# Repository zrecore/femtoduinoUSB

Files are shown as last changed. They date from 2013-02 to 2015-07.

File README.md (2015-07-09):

femtoduinoUSB
=============

Latest revision: FemtoduinoUSB r14.2

See the FemtoduinoUSB_r14 folder. It is a 4-layer EAGLE PCB design + schematic.

FemtoduinoUSB ATMEGA328P-MU Arduino Clone. Originally based on the Femtoduino by Fabio Varesano. Modified by Alex Albino to include FTDI USB to serial integration.

The femtoduino, and femtoduinoUSB is released under the following license: 

   CC-BY-SA 3.0 Unported
   http://creativecommons.org/licenses/by-sa/3.0/

The USB to UART circuit was completed in part thanks to Jim Paris' super-awesome MicroFTX schematics (http://jim.sh/ftx/), which are released under the following license:

   Creative Commons Attribution-ShareAlike 3.0 Unported License
   http://creativecommons.org/licenses/by-sa/3.0/
The pins on the latest revision are corrected to align perfectly with the original Femtoduino pin positions.

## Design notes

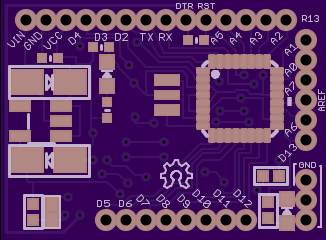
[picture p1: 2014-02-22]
FemtoduinoUSB_r13/femtoduino-usb_front.png

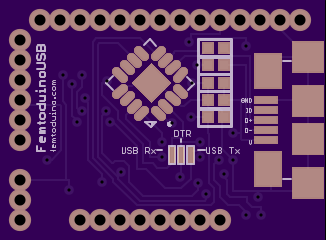
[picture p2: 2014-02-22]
FemtoduinoUSB_r13/femtoduino-usb_back.png

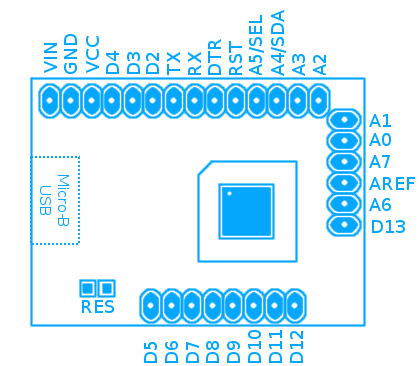
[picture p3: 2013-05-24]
FemtoduinoUSB_r13/femtoduinoUSB_pins.png

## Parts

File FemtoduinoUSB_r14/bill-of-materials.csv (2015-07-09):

Qty | Value | Device/Manufacturer | Package | Parts | Description
7 | 0.1uF | C1005X7R1A104K050BB | 0402 | C1, C2, C3, C4, C5, C6, C7 | Ceramic Capacitors
1 | DNP |  |  | U$4
1 | DNP |  |  | U$2
1 | DNP |  |  | U$3
1 | DNP |  |  | U$28
1 | 10K | CRCW040210K0JNEDHP | _0402 | R4 | Resistors
2 | 10uF | TAJA106K016RNJ | EIA3216-18/A-R | C8, C9 | Tantalum Capacitors
2 | 27 | CRCW040227R0FKED | 0402 | R1, R2 | Resistors
2 | 330 | CRCW0402330RJNED | 0402 | R3, R5 | Resistors
1 | ATMEGA328MLF | ATMEGA328P-MU | MLF32 | U1 | Atmel 32-pin 8-bit micro, 32k flash.
1 | 16MHz | CSTCE16M0V51-R0 | CSTCE16M0V51-R0_PACKAGE | U$22 | This is the CSTCE16M0V51-R0 Murata resonator (CERALOCK) 16Mhz 0.5% Tolerance
1 | GREEN | 598-8070-102F | 0603 | LED2 | LED
1 | FT230XQ | FT230XQ-R | QFN-16 | U$1
1 | LDO_REGULATOR | TPS76350DBVR | SOT-23-5 | U$10
1 | RED | 598-8010-102F | 0603 | LED1 | LED
1 | DNP |  |  | U$17
1 | USB_MICROB | ZX62-B-5PA(11) | USB_MICROB_PACKAGE | U$6 | This is the hirose ZX62-B-5PA(11) MICRO-USB B Type female connection.

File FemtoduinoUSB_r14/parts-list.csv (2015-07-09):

Part | Value | Device/Manufacturer | Package | Description
C1 | 0.1uF | C1005X7R1A104K050BB | 0402 | Ceramic Capacitors
C2 | 0.1uF | C1005X7R1A104K050BB | 0402 | Ceramic Capacitors
C3 | 0.1uF | C1005X7R1A104K050BB | 0402 | Ceramic Capacitors
C4 | 0.1uF | C1005X7R1A104K050BB | 0402 | Ceramic Capacitors
C5 | 0.1uF | C1005X7R1A104K050BB | 0402 | Ceramic Capacitors
C6 | 0.1uF | C1005X7R1A104K050BB | 0402 | Ceramic Capacitors
C7 | 0.1uF | C1005X7R1A104K050BB | 0402 | Ceramic Capacitors
C8 | 10uF | TAJA106K016RNJ | EIA3216-18/A-R | Tantalum Capacitors
C9 | 10uF | TAJA106K016RNJ | EIA3216-18/A-R | Tantalum Capacitors
LED1 | RED | 598-8010-102F | 0603 | LED
LED2 | GREEN | 598-8070-102F | 0603 | LED
R1 | 27 | CRCW040227R0FKED | 0402 | Resistors
R2 | 27 | CRCW040227R0FKED | 0402 | Resistors
R3 | 330 | CRCW0402330RJNED | 0402 | Resistors
R4 | 10K | CRCW040210K0JNEDHP | 0402 | Resistors
R5 | 330 | CRCW0402330RJNED | 0402 | Resistors
U$1 | FT230XQ | FT230XQ-R | QFN-16
U$2 | DNP
U$3 | DNP
U$4 | DNP
U$6 | USB_MICROB | ZX62-B-5PA(11) | USB_MICROB_PACKAGE | This is the hirose ZX62-B-5PA(11) MICRO-USB B Type female connection.
U$10 | LDO_REGULATOR | TPS76350DBVR | LDO_REGULATOR
U$17 | DNP
U$22 | 16MHz | CSTCE16M0V51-R0 | CSTCE16M0V51-RO_PACKAGE | This is the CSTCE16M0V51-R0 Murata resonator (CERALOCK) 16Mhz 0.5% Tolerance
U$28 | DNP
U1 | ATMEGA328MLF | ATMEGA328P-MU | MLF32 | Atmel 32-pin 8-bit micro, 32k flash.

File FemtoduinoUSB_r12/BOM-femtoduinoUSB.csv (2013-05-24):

Part | Value | Device | Mfr. | Mfr.# | Package | Description
C1 | 10uF | CAP_TANTALUMB/3528_WAVE | AVX | TAJA106K016RNJ | EIA3528-21/B-W | Tantalum Capacitors
C2 | 10uF | CAP_TANTALUMB/3528_WAVE | AVX | TAJA106K016RNJ | EIA3528-21/B-W | Tantalum Capacitors
C3 | 0.1uF | CAP_CERAMIC0402 | TDK | C1005X7R1A104K | 402 | Ceramic Capacitors
C4 | 0.1uF | CAP_CERAMIC0402 | TDK | C1005X7R1A104K | 402 | Ceramic Capacitors
C5 | 0.1uF | CAP_CERAMIC0402 | TDK | C1005X7R1A104K | 402 | Ceramic Capacitors
C6 | 0.1uF | CAP_CERAMIC0402 | TDK | C1005X7R1A104K | 402 | Ceramic Capacitors
C7 | 0.1uF | CAP_CERAMIC0402 | TDK | C1005X7R1A104K | 402 | Ceramic Capacitors
C8 | 0.1uF | CAP_CERAMIC0402 | TDK | C1005X7R1A104K | 402 | Ceramic Capacitors
C9 | 0.1uF | CAP_CERAMIC0402 | TDK | C1005X7R1A104K | 402 | Ceramic Capacitors
IC1 |  | ATMEGA168MLF | Atmel | ATMEGA328P-MU | MLF32 | Atmel 32-pin 8-bit micro | 16k flash.
LED1 | D1 | LED0805 | Dialight | 598-8110-107F | CHIPLED_0805 | LED
LED2 |  | LED0805 | Dialight | 598-8170-107F | CHIPLED_0805 | LED
R1 | 330 | RESISTOR0402 | Vishay | CRCW0402330RJNED | 402 | Resistors
R2 | 10K | RESISTOR0402 | Vishay | CRCW040210K0JNEDHP | 402 | Resistors
R3 | 330 | RESISTOR0402 | Vishay | CRCW0402330RJNED | 402 | Resistors
R4 | 27 | RESISTOR0402 | Vishay | CRCW040227R0FKED | 402 | Resistors
R5 | 27 | RESISTOR0402 | Vishay | CRCW040227R0FKED | 402 | Resistors
SJ1 | SPST_SMD | SPST_SMD |  |  | SPST_SMD
SJ2 | SPST_SMD | SPST_SMD |  |  | SPST_SMD
SJ3 | SPST_SMD | SPST_SMD |  |  | SPST_SMD
SJ4 | SPST_SMD | SPST_SMD |  |  | SPST_SMD
U$2 | 05_PINHEAD_1X6 | 05_PINHEAD_1X6 |  |  | 05_PINHEAD_1X6_PACKAGE
U$3 | 05_PINHEAD_1X8 | 05_PINHEAD_1X8 |  |  | 05_PINHEAD_1X8_PACKAGE
U$4 | 05_PINHEAD_1X14 | 05_PINHEAD_1X14 |  |  | 05_PINHEAD_1X14_PACKAGE
U$5 | CSTCE16MOV51-RO | CSTCE16MOV51-RO | Murata | CSTCE16M0V51-R0 | CSTCE16M0V51-RO_PACKAGE | This is the CSTCE16M0V51-R0 Murata resonator (CERALOCK) 16Mhz 0.5% Tolerance
U$6 | SPST_SMD | SPST_SMD |  |  | SPST_SMD
U$7 | FT230XQ | FT230XQ | FTDI | FT230XQ-R | FT230XQ
U1 | MIC5205 | LDO_REGULATOR | Texas Instruments | TPS76350DBVR | LDO_REGULATOR
USB1 | USB_MICROB | USB_MICROB | Hirose Electric | ZX62-B-5PA(11) | USB_MICROB_PACKAGE | This is the hirose ZX62-B-5PA(11) MICRO-USB B Type female connection.

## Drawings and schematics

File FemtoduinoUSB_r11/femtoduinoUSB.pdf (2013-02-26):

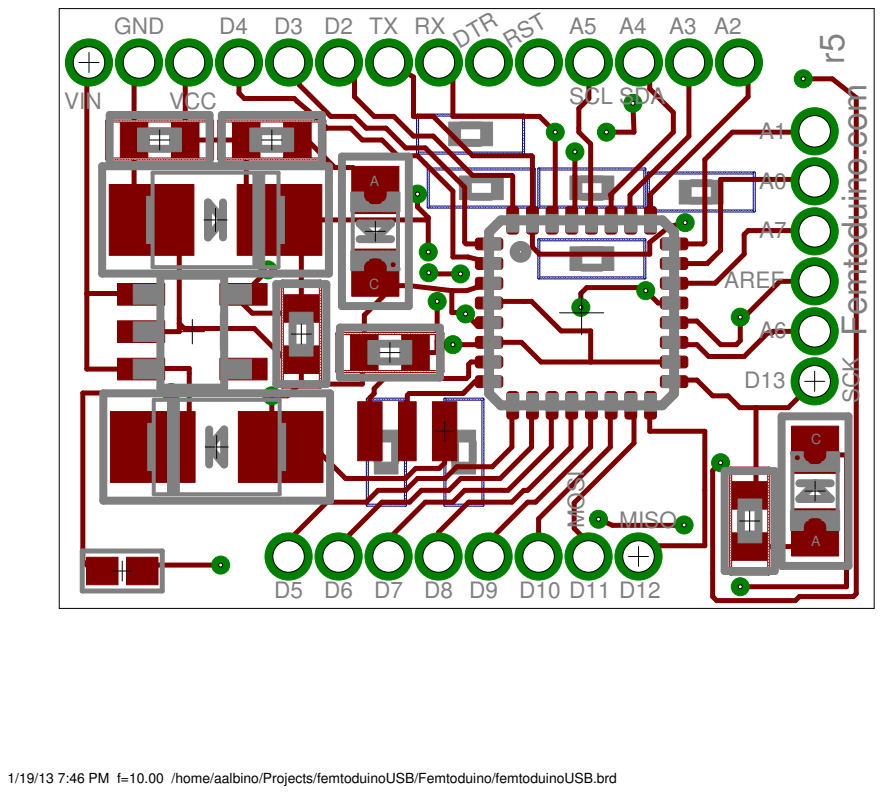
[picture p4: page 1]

1/19/13 7:46 PM f=10.00 /home/aalbino/Projects/femtoduinoUSB/Femtoduino/femtoduinoUSB.brd

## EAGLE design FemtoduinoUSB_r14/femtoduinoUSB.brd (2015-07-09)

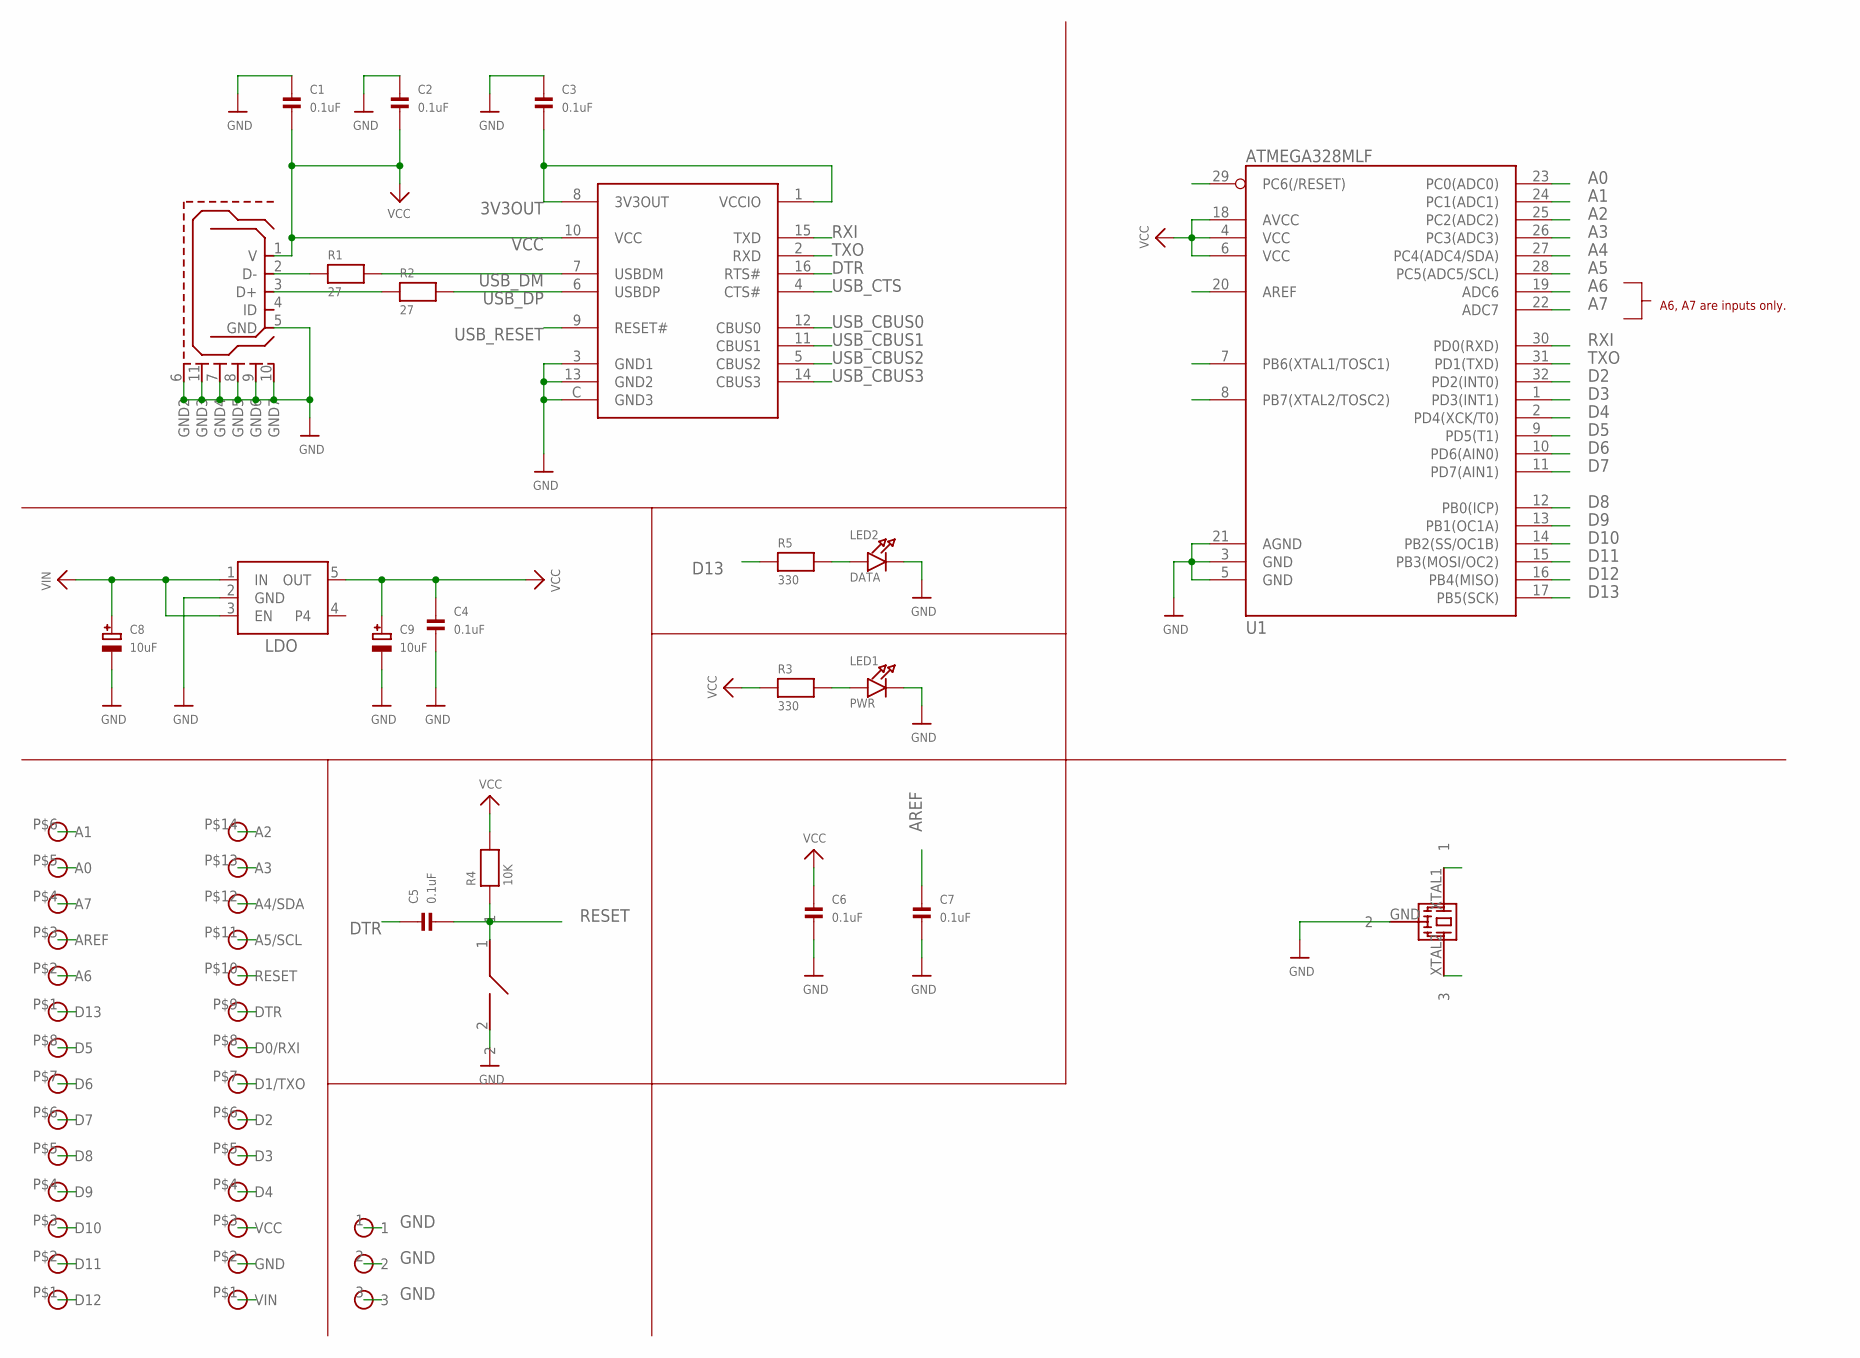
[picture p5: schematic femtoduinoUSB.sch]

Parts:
C1, C2, C3, C4, C5, C6, C7: 0.1uF; _0402MP
C8, C9: 10uF; EIA3216-18/A-R
LED1: PWR; CHIPLED_0603_NOOUTLINE
LED2: DATA; CHIPLED_0603_NOOUTLINE
R1, R2: 27; _0402MP
R3, R5: 330; _0402MP
R4: 10K; _0402
U1: ATMEGA328MLF; MLF32
U$1: FT230XQ
U$2: 05_PINHEAD_1X6; 05_PINHEAD_1X6_PACKAGE
U$3: 05_PINHEAD_1X8; 05_PINHEAD_1X8_PACKAGE
U$4: 05_PINHEAD_1X14; 05_PINHEAD_1X14_PACKAGE
U$6: USB_MICROB; USB_MICROB_PACKAGE
U$10: LDO_REGULATOR
U$17: SPST_SMD
U$22: CSTCE16MOV51-RO; CSTCE16M0V51-RO_PACKAGE
U$28: 05_PINHEAD_HEADER_1X3; 05_PINHEAD_1X3_HEAD_PACKAGE

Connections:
3V3OUT: C3.2, U$1.1 (VCCIO), U$1.8 (3V3OUT)
A0: U1.23 (PC0(ADC0)), U$2.P$5 (A0)
A1: U1.24 (PC1(ADC1)), U$2.P$6 (A1)
A2: U1.25 (PC2(ADC2)), U$4.P$14 (A2)
A3: U1.26 (PC3(ADC3)), U$4.P$13 (A3)
A4: U1.27 (PC4(ADC4/SDA)), U$4.P$12 (A4/SDA)
A5: U1.28 (PC5(ADC5/SCL)), U$4.P$11 (A5/SCL)
A6: U1.19 (ADC6), U$2.P$2 (A6)
A7: U1.22 (ADC7), U$2.P$4 (A7)
AREF: C7.1, U1.20 (AREF), U$2.P$3 (AREF)
D2: U1.32 (PD2(INT0)), U$4.P$6 (D2)
D3: U1.1 (PD3(INT1)), U$4.P$5 (D3)
D4: U1.2 (PD4(XCK/T0)), U$4.P$4 (D4)
D5: U1.9 (PD5(T1)), U$3.P$8 (D5)
D6: U1.10 (PD6(AIN0)), U$3.P$7 (D6)
D7: U1.11 (PD7(AIN1)), U$3.P$6 (D7)
D8: U1.12 (PB0(ICP)), U$3.P$5 (D8)
D9: U1.13 (PB1(OC1A)), U$3.P$4 (D9)
D10: U1.14 (PB2(SS/OC1B)), U$3.P$3 (D10)
D11: U1.15 (PB3(MOSI/OC2)), U$3.P$2 (D11)
D12: U1.16 (PB4(MISO)), U$3.P$1 (D12)
D13: R5.1, U1.17 (PB5(SCK)), U$2.P$1 (D13)
DTR: C5.1, U$1.16 (RTS#), U$4.P$9 (DTR)
GND: C1.1, C2.1, C3.1, C4.2, C6.2, C7.2, C8.-, C9.-, LED1.C, LED2.C, U1.3 (GND), U1.5 (GND), U1.21 (AGND), U$1.3 (GND1), U$1.13 (GND2), U$1.C (GND3), U$4.P$2 (GND), U$6.5 (GND), U$6.6 (GND2), U$6.7 (GND4), U$6.8 (GND5), U$6.9 (GND6), U$6.10 (GND7), U$6.11 (GND3), U$10.2 (GND), U$17.2, U$22.GND (2), U$28.1, U$28.2, U$28.3
unnamed: R1.1, U$6.2 (D-)
unnamed: R2.1, U$6.3 (D+)
unnamed: LED2.A, R5.2
unnamed: LED1.A, R3.2
RESET: C5.2, R4.1, U1.29 (PC6(/RESET)), U$4.P$10 (RESET), U$17.1
RXI: U1.30 (PD0(RXD)), U$1.15 (TXD), U$4.P$8 (D0/RXI)
TXO: U1.31 (PD1(TXD)), U$1.2 (RXD), U$4.P$7 (D1/TXO)
USB_CBUS0: U$1.12 (CBUS0)
USB_CBUS1: U$1.11 (CBUS1)
USB_CBUS2: U$1.5 (CBUS2)
USB_CBUS3: U$1.14 (CBUS3)
USB_CTS: U$1.4 (CTS#)
USB_DM: R1.2, U$1.7 (USBDM)
USB_DP: R2.2, U$1.6 (USBDP)
USB_RESET: U$1.9 (RESET#)
VCC: C1.2, C2.2, C4.1, C6.1, C9.+, R3.1, R4.2, U1.4 (VCC), U1.6 (VCC), U1.18 (AVCC), U$1.10 (VCC), U$4.P$3 (VCC), U$6.1 (V), U$10.5 (OUT)
VIN: C8.+, U$4.P$1 (VIN), U$10.1 (IN), U$10.3 (EN)
XTAL1: U1.7 (PB6(XTAL1/TOSC1)), U$22.XTAL1 (1)
XTAL2: U1.8 (PB7(XTAL2/TOSC2)), U$22.XTAL2 (3)

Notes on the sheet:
A6, A7 are inputs only.

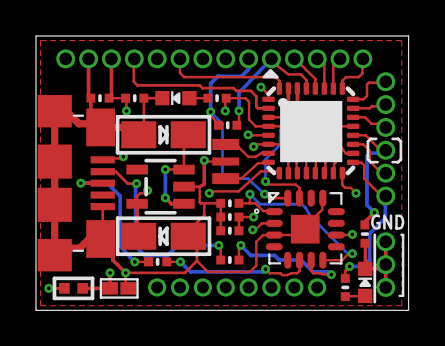
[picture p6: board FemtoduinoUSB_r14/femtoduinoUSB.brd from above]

Board: 4 copper layers, 20.7 x 15.2 mm, 27 parts (1 on the bottom side), 37 nets.

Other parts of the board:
U$29: OSHW_6X70_NOTEXT

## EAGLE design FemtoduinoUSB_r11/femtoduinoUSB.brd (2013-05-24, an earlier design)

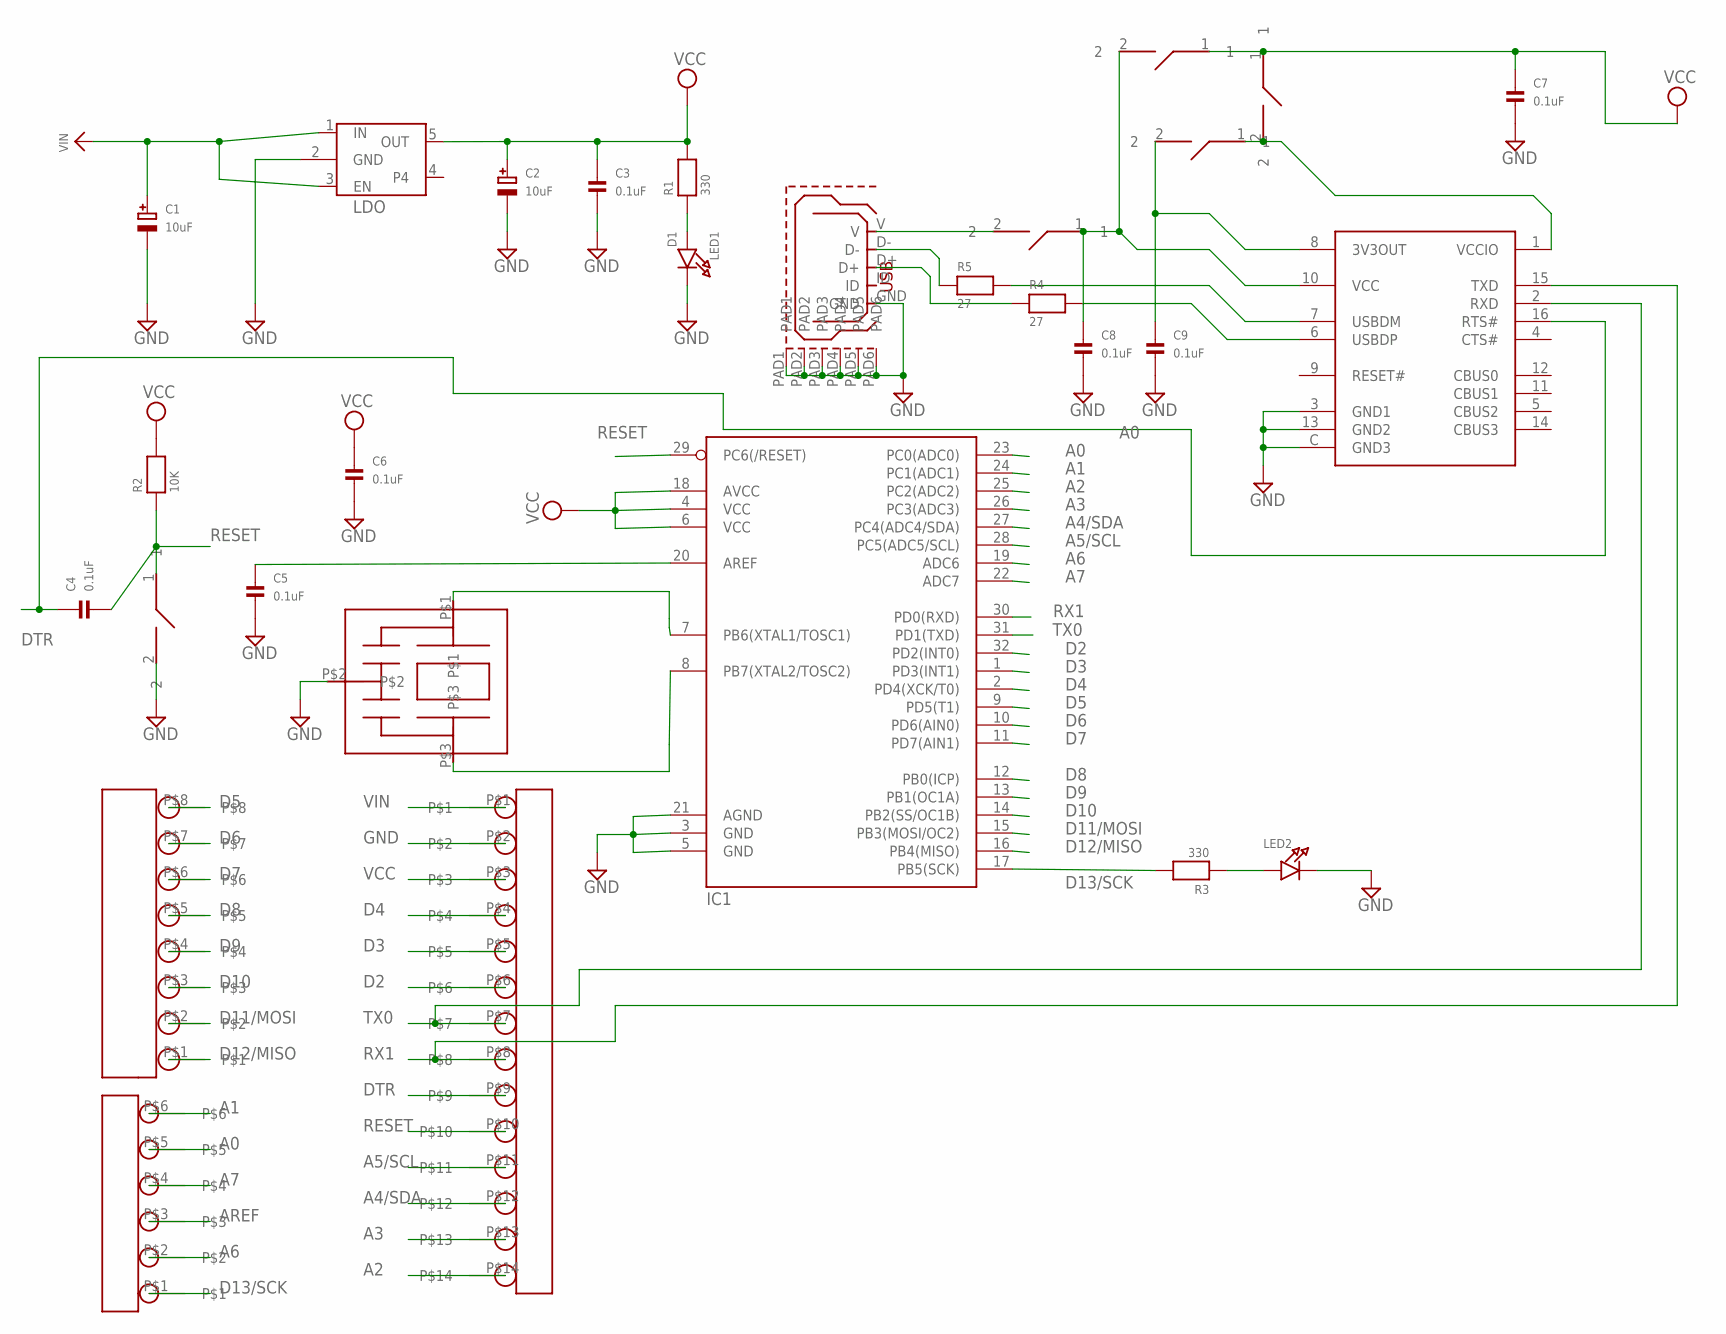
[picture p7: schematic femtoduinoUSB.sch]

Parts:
C1, C2: 10uF; EIA3528-21/B-W
C3, C4, C5, C6, C7, C8, C9: 0.1uF; 0402
IC1: ATMEGA168MLF; MLF32
LED1: D1; CHIPLED_0805
LED2: LED0805; CHIPLED_0805
R1, R3: 330; 0402
R2: 10K; 0402
R4, R5: 27; 0402
SJ1, SJ2, SJ3, SJ4: SPST_SMD
U1: MIC5205; LDO_REGULATOR
U$2: 05_PINHEAD_1X6; 05_PINHEAD_1X6_PACKAGE
U$3: 05_PINHEAD_1X8; 05_PINHEAD_1X8_PACKAGE
U$4: 05_PINHEAD_1X14; 05_PINHEAD_1X14_PACKAGE
U$5: CSTCE16MOV51-RO; CSTCE16M0V51-RO_PACKAGE
U$6: SPST_SMD
U$7: FT230XQ
USB1: USB_MICROB; USB_MICROB_PACKAGE

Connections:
3V3OUT: C9.1, SJ4.2, U$7.8 (3V3OUT)
A0: IC1.23 (PC0(ADC0)), U$2.P$5
A1: IC1.24 (PC1(ADC1)), U$2.P$6
A2: IC1.25 (PC2(ADC2)), U$4.P$14
A3: IC1.26 (PC3(ADC3)), U$4.P$13
A4/SDA: IC1.27 (PC4(ADC4/SDA)), U$4.P$12
A5/SCL: IC1.28 (PC5(ADC5/SCL)), U$4.P$11
A6: IC1.19 (ADC6), U$2.P$2
A7: IC1.22 (ADC7), U$2.P$4
AREF: C5.1, IC1.20 (AREF), U$2.P$3
D2: IC1.32 (PD2(INT0)), U$4.P$6
D3: IC1.1 (PD3(INT1)), U$4.P$5
D4: IC1.2 (PD4(XCK/T0)), U$4.P$4
D5: IC1.9 (PD5(T1)), U$3.P$8
D6: IC1.10 (PD6(AIN0)), U$3.P$7
D7: IC1.11 (PD7(AIN1)), U$3.P$6
D8: IC1.12 (PB0(ICP)), U$3.P$5
D9: IC1.13 (PB1(OC1A)), U$3.P$4
D10: IC1.14 (PB2(SS/OC1B)), U$3.P$3
D11/MOSI: IC1.15 (PB3(MOSI/OC2)), U$3.P$2
D12/MISO: IC1.16 (PB4(MISO)), U$3.P$1
D13/SCK: IC1.17 (PB5(SCK)), R3.2, U$2.P$1
D+: R4.2, U$7.6 (USBDP)
D-: R5.2, U$7.7 (USBDM)
DTR: C4.1, U$4.P$9, U$7.16 (RTS#)
GND: C1.-, C2.-, C3.2, C5.2, C6.2, C7.2, C8.2, C9.2, IC1.3 (GND), IC1.5 (GND), IC1.21 (AGND), LED1.C, LED2.C, U1.2 (GND), U$4.P$2, U$5.P$2, U$6.2, U$7.3 (GND1), U$7.13 (GND2), U$7.C (GND3), USB1.GND, USB1.PAD1, USB1.PAD2, USB1.PAD3, USB1.PAD4, USB1.PAD5, USB1.PAD6
unnamed: R4.1, USB1.D+
unnamed: R5.1, USB1.D-
unnamed: LED1.A, R1.1
unnamed: LED2.A, R3.1
PB6: IC1.7 (PB6(XTAL1/TOSC1)), U$5.P$1
PB7: IC1.8 (PB7(XTAL2/TOSC2)), U$5.P$3
RESET: C4.2, IC1.29 (PC6(/RESET)), R2.1, U$4.P$10, U$6.1
RX1: IC1.30 (PD0(RXD)), U$4.P$8, U$7.15 (TXD)
TX0: IC1.31 (PD1(TXD)), U$4.P$7, U$7.2 (RXD)
VCC: C2.+, C3.1, C6.1, C7.1, IC1.4 (VCC), IC1.6 (VCC), IC1.18 (AVCC), R1.2, R2.2, SJ1.2, SJ2.1, SJ3.1, U1.5 (OUT), U$4.P$3, USB1.V
VCCIO: SJ3.2, SJ4.1, U$7.1 (VCCIO)
VIN: C1.+, U1.1 (IN), U1.3 (EN), U$4.P$1
V_VCC: C8.1, SJ1.1, SJ2.2, U$7.10 (VCC)

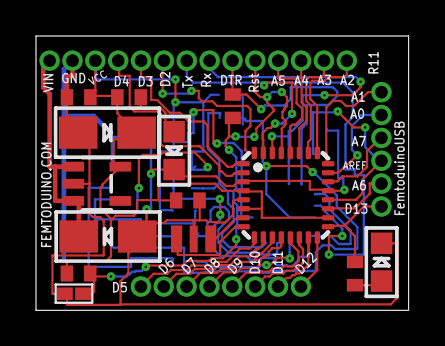
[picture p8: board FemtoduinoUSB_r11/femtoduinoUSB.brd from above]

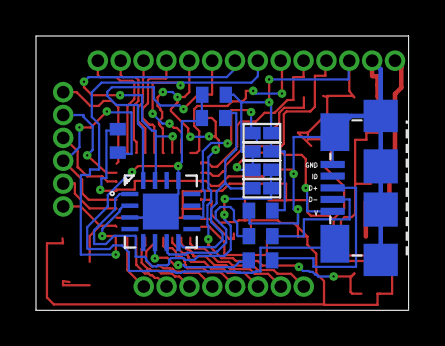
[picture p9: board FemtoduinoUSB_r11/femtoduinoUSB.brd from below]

Board: 2 copper layers, 20.7 x 15.2 mm, 29 parts (12 on the bottom side), 39 nets.

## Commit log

2012-12-25 Adding the femtoduinoUSB eagle cad files.
    [femtoduinoUSB.brd, femtoduinoUSB.sch]
2013-01-14 Updates to the FemtoduinoUSB board
2013-02-26 Committing revision 9B of the FemtoduinoUSB. Minor corrections to the schematic, as the FTDI chip RESET# line was erroneously connected, instead of RST, to the ATMEGA DTR line. Additionally, a wire i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
    [femtoduinoUSB.brd, femtoduinoUSB.sch]
2013-03-17 Adding revision 9C
    [femtoduinoUSB.brd]
2013-03-21 Committing changes to revision 9C, adding revision 10 with FTDI chip FT230 instead of FT231
    [femtoduinoUSB.brd, femtoduinoUSB.sch]
2013-04-08 Committing revision 11
    [femtoduinoUSB.brd, femtoduinoUSB.sch]
2013-04-16 FTDI chip footprint update
2013-05-24 Revision 12 - slightly enlarged through hole vias to make fabrication easier
    [BOM-femtoduinoUSB.csv, femtoduinoUSB.brd, femtoduinoUSB.sch]
2014-02-22 Adding revision 13 of the FemtoduinoUSB board
    [femtoduinoUSB.brd, femtoduinoUSB.sch]
2015-01-15 Adding in FemtoduinoUSB revision 13 schematics and board file (EAGLE PCB)
2015-07-09 Releasing revision 14.2 of the Femtoduino USB (AVR powered, Arduino UNO compatible)
    [femtoduinoUSB.brd, femtoduinoUSB.sch]
2015-07-09 Adding bill of materials for r14.2
    [bill-of-materials.csv]
2015-07-09 Minor update to Bill of Materials, adding parts list
    [bill-of-materials.csv, parts-list.csv]

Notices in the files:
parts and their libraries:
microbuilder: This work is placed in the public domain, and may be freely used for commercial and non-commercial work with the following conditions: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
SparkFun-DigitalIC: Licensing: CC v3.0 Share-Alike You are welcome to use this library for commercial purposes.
